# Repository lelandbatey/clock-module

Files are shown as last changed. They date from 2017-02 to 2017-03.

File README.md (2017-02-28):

Clock-module
============

This repo contains PCB designs for the first component of Ben Eater's
educational 8-bit CPU, the clock module. You can [watch Mr. Eaters *fantastic*
series on designing and building this CPU on his Youtube
channel.](https://www.youtube.com/user/eaterbc/videos)

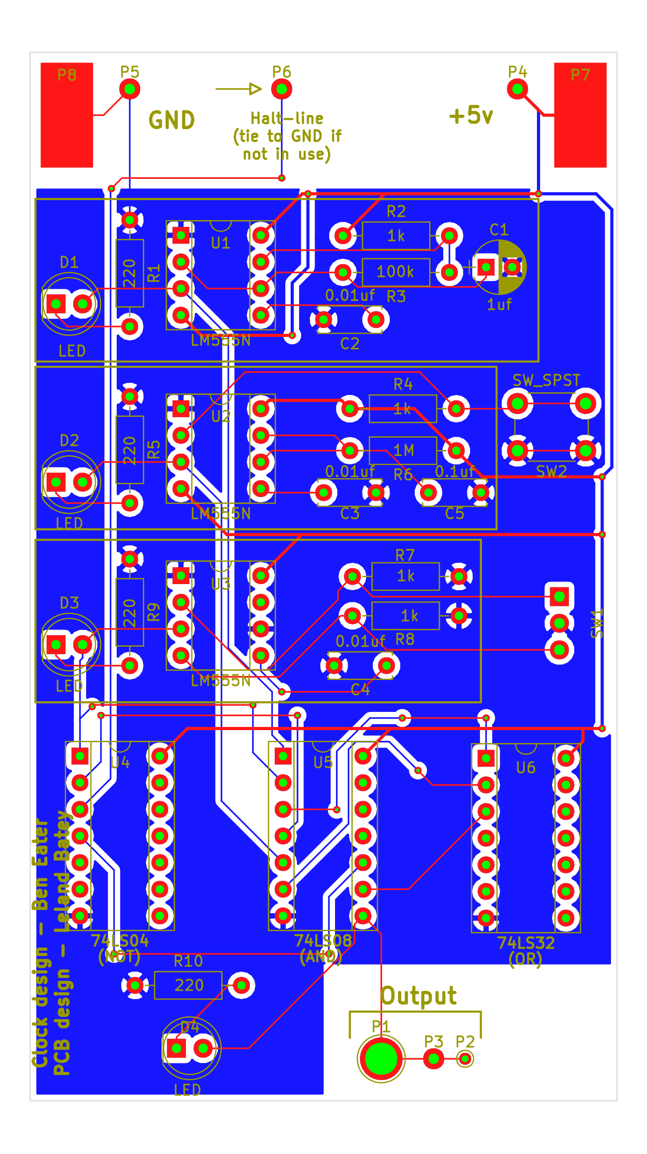
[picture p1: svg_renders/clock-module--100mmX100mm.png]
Render of clock module PCB


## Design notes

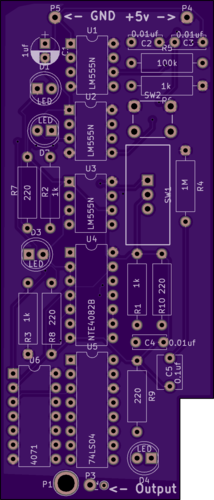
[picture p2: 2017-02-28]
preview-osh-park.png

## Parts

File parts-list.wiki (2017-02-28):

Parts list for clock module
---------------------------

| Part name | Count | Unit Price | Total price |
|---|---|---|---|
| Resistors (assorted)  | 10 | $0.16 | $1.60 |
| Push button | 1 | $0.50 | $0.50 |
| Slide switch | 1 | $0.39 | $0.39 |
| 74LS04 (Hex inverter) | 1 | $0.62 | $0.62 |
| 74LS08 (Quad AND) | 1 | $0.56 | $0.56 |
| 74LS32 (Quad OR) | 1 | $0.52 | $0.52 |
| LM555 (timer) | 3 | $0.34 | $1.02 |
| LED (Yellow) | 4 | $0.45 | $1.80 |
| 14 pin IC socket | 3 | $0.21 | $0.63 |
| 8 pin IC socket | 3 | $0.18 | $0.54 |
| 0.01uF Capacitor | 4 | $0.15 | $0.60 |
| 0.1uF Capacitor | 1 | $0.10 | $0.10 |
| 1uF Capacitor | 1 | $0.10 | $0.10 |

Total:  $8.98

1.60 + 0.50 + 0.39 + 0.62 + 0.56 + 0.52 + 1.02 + 1.80 + 0.63 + 0.54 + 0.60 + 0.10 + 0.10

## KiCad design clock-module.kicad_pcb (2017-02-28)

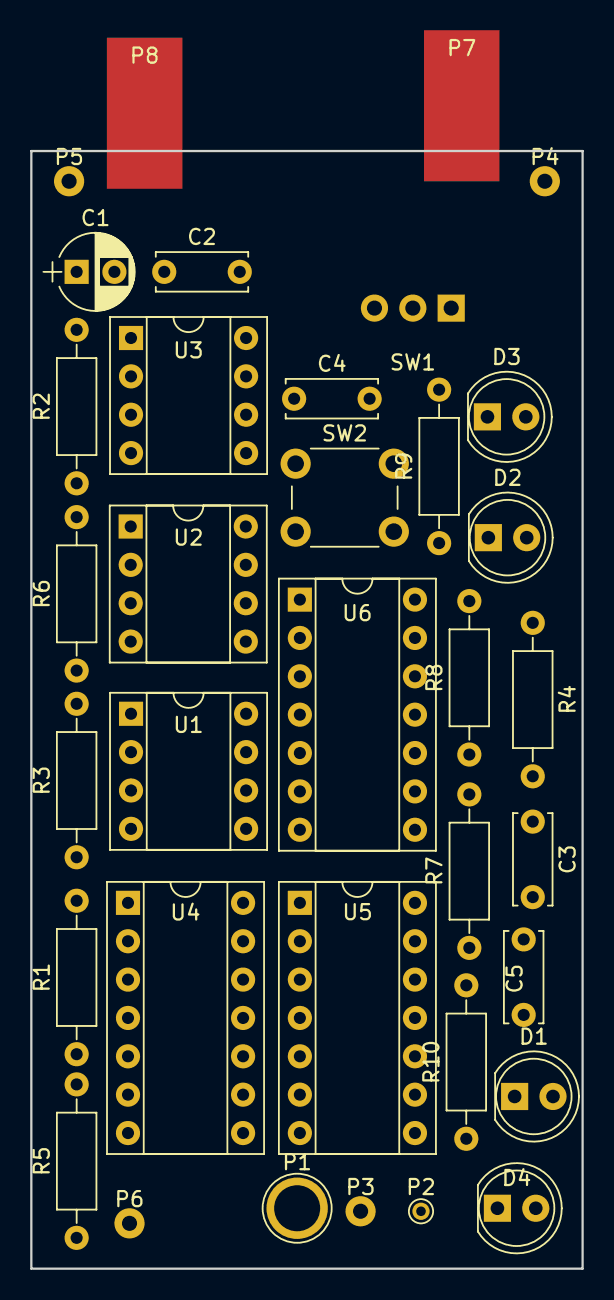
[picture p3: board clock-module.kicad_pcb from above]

Board: 2 copper layers, 36.5 x 74.0 mm, 35 parts (0 on the bottom side), 25 nets, no tracks yet.

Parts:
C1: 1uf; CP_Radial_D5.0mm_P2.50mm
C2, C3, C4: 0.01uf; C_Disc_D6.0mm_W2.5mm_P5.00mm
C5: 0.1uf; C_Disc_D6.0mm_W2.5mm_P5.00mm
D1, D2, D3, D4: LED; LED_D5.0mm
P1: CONN_01X01; 1pin
P2: CONN_01X01; PINTST
P3, P4, P5, P6: CONN_01X01; test_pin_single_hole
P7, P8: CONN_01X01; SolderWirePad_single_SMD_5x10mm
R1, R2, R3, R6: 1k; R_Axial_DIN0207_L6.3mm_D2.5mm_P10.16mm_Horizontal
R4: 1M; R_Axial_DIN0207_L6.3mm_D2.5mm_P10.16mm_Horizontal
R5: 100k; R_Axial_DIN0207_L6.3mm_D2.5mm_P10.16mm_Horizontal
R7, R8, R9, R10: 220; R_Axial_DIN0207_L6.3mm_D2.5mm_P10.16mm_Horizontal
SW1: SW_SPDT; SPDT_L15mm_W8mm
SW2: SW_SPST; SW_PUSH_6mm
U1, U2, U3: LM555N; DIP-8_W7.62mm_Socket
U4: 74LS04; DIP-14_W7.62mm_Socket
U5: 74LS08; DIP-14_W7.62mm_Socket
U6: 74LS32; DIP-14_W7.62mm_Socket

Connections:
+5V: P4.1, P7.1, R3.1, R4.1, R6.1, SW2.1, U1.4, U1.8, U2.4, U2.8, U3.8, U4.14, U5.14, U6.14
GND: C1.2, C2.2, C3.2, C4.2, C5.1, P5.1, P8.1, R1.1, R2.2, R7.1, R8.1, R9.1, R10.1, SW1.2, U1.1, U2.1, U3.1, U3.6, U4.7, U5.7, U6.7
unnamed: C1.1, R5.2, U1.2, U1.6
unnamed: C2.1, U1.5
unnamed: C3.1, U2.5
unnamed: C4.1, U3.5
unnamed: C5.2, R4.2, U2.6, U2.7
unnamed: D1.1, R7.2
unnamed: D1.2, U1.3, U5.1
unnamed: D2.1, R8.2
unnamed: D2.2, U2.3, U5.5
unnamed: D3.1, R9.2
unnamed: D3.2, U3.3, U4.1, U5.2
unnamed: D4.1, R10.2
unnamed: D4.2, P1.1, P2.1, P3.1, U5.8
unnamed: P6.1, U4.3
unnamed: R1.2, SW1.1, U3.2
unnamed: R2.1, SW1.3, U3.4
unnamed: R3.2, SW2.2, U2.2
unnamed: R5.1, R6.2, U1.7
unnamed: U4.2, U5.4
unnamed: U4.4, U5.10
unnamed: U5.3, U6.1
unnamed: U5.6, U6.2
unnamed: U5.9, U6.3

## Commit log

2017-02-28 Initial commit, adding existing files
    [clock-module--100mmX100mm.kicad_pcb, clock-module.kicad_pcb, clock-module.sch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]
2017-02-28 Add README with PCB image
    [clock-module--100mmX100mm-B.Cu.gbl, clock-module--100mmX100mm-F.Cu.gtl]
2017-03-01 Improve pad clearences, aligator clip improvements
    [clock-module--100mmX100mm.kicad_pcb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]
2017-03-26 Fix bug in board layout
    [clock-module--100mmX100mm.kicad_pcb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]
